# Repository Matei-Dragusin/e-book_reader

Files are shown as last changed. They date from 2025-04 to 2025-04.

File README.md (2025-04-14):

# README

## Diagrama bloc
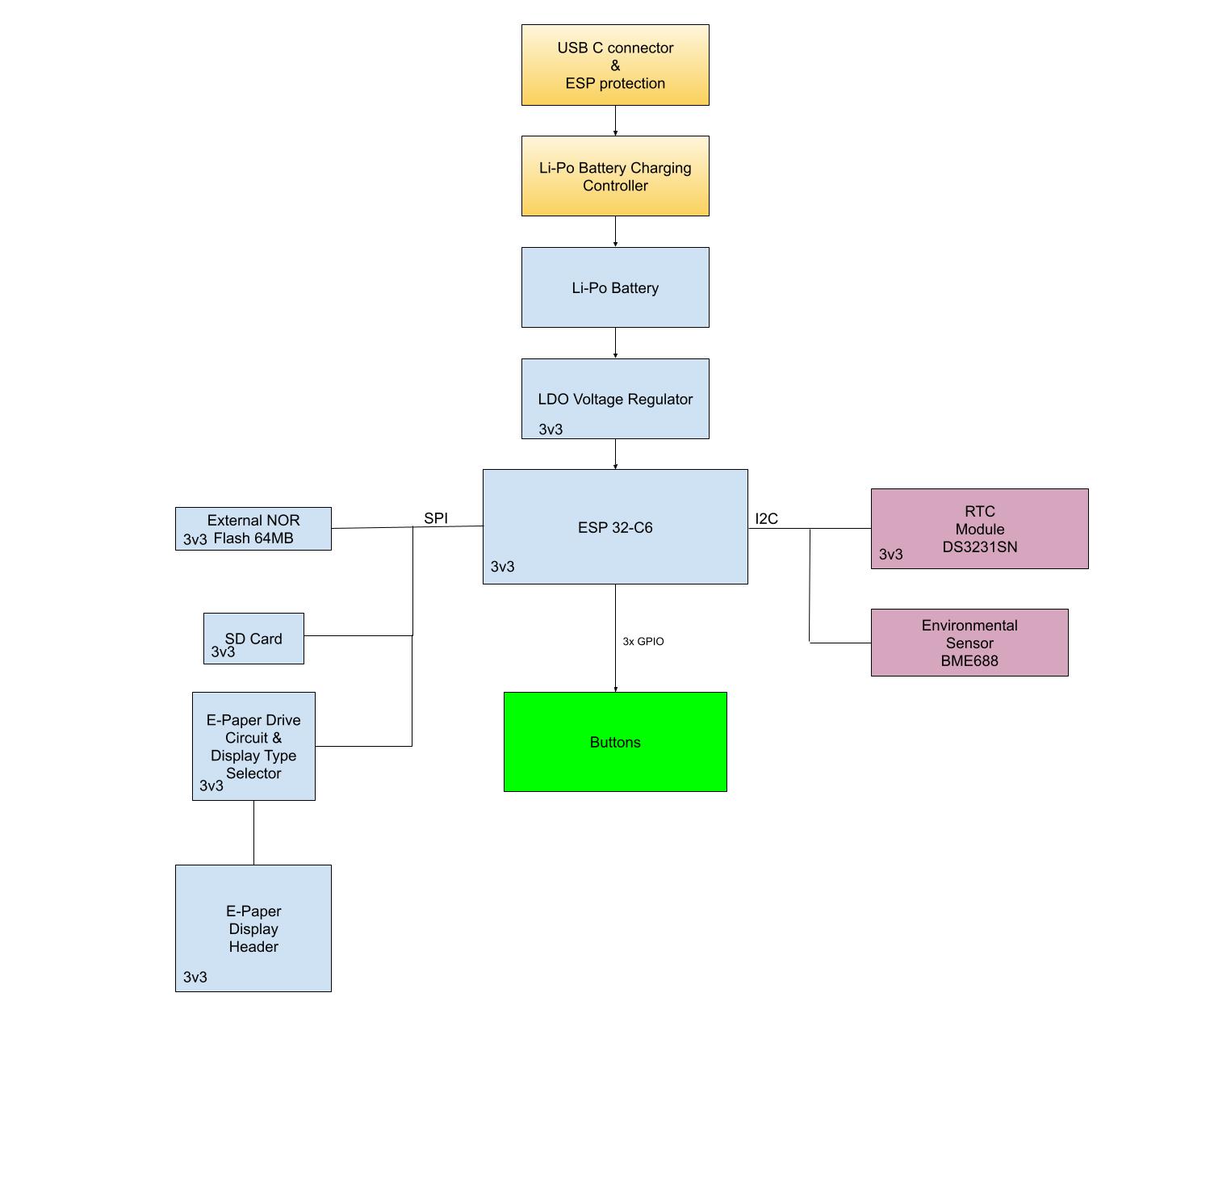
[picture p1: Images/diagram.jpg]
Diagrama Bloc
 

---
## Bill Of Materials (BOM)
| Componentă | Procurare | Datasheet |
|---|---|---|
| Button | [Mouser](https://ro.mouser.com/ProductDetail/CK/KMR221GULCLFS?qs=u2NJ%252B70r0goBXaNk7IrU0Q%3D%3D) |[Datasheet](https://www.ckswitches.com/media/1479/kmr2.pdf)|
| Capacitor SUPERCAP | [Mouser](https://ro.mouser.com/ProductDetail/Seiko-Semiconductors/CPH3225A?qs=3etwrb1wR%252BhUOph6lAO7eg%3D%3D) | [Datasheet](https://ro.mouser.com/datasheet/2/360/Seiko_Instruments_MicroBattery_E_20230330_2024Jan_-3561061.pdf)|
| Capacitor 100nF | [Mouser](https://ro.mouser.com/ProductDetail/KEMET/C0402C104K4RAL?qs=pIZUS6sqCWCaMuP2QVR%2Fog%3D%3D) | [Datasheet](https://ro.mouser.com/datasheet/2/447/KEM_C1018_X7R_SnPb_SMD-3316276.pdf)|
| Capacitor 4.7uF | [Mouser](https://ro.mouser.com/ProductDetail/KEMET/C0402C475M9PAC7411?qs=cpo3%2FpBou2jRzZxyxJnMGg%3D%3D) | [Datasheet](https://ro.mouser.com/datasheet/2/447/KEM_C1006_X5R_SMD-3316465.pdf)|
| Capacitor 100uF TANT | [Mouser](https://ro.mouser.com/ProductDetail/KYOCERA-AVX/TAJW107M010RNJ?qs=Wtp%252Bf%2FAeVqIH8v1VxV%252B1Rg%3D%3D) | [Datasheet](https://ro.mouser.com/datasheet/2/40/TAJ-3165264.pdf)|
| Capacitor 4.7uF / 25V | [Mouser](https://ro.mouser.com/ProductDetail/KYOCERA-AVX/12063C475KAZ2A?qs=%252BdQmOuGyFcG3LdbVp5waMw%3D%3D) | [Datasheet](https://ro.mouser.com/datasheet/2/40/X7RDielectric-2943470.pdf)|
| Capacitor 1uF | [Mouser](https://ro.mouser.com/ProductDetail/KEMET/C0402C105K9PACTU?qs=UdQET6xYxVCMExqTDkuPeQ%3D%3D) | [Datasheet](https://ro.mouser.com/datasheet/2/447/KEM_C1006_X5R_SMD-3316465.pdf)|
| Capacitor 10uF | [Mouser](https://ro.mouser.com/ProductDetail/KEMET/C0402C106M9PACTU?qs=x4XeXhDQKnp%252Bz0lMlwMC3A%3D%3D) | [Datasheet](https://ro.mouser.com/datasheet/2/447/KEM_C1006_X5R_SMD-3316465.pdf)|
| CHG_LED | [CPC](https://cpc.farnell.com/kingbright/kpg-1608zgc/led-smd-0603-grn/dp/SC20796) | [Datasheet](https://www.farnell.com/datasheets/2046349.pdf)|
| USBLC6-2SC6Y | [Mouser](https://ro.mouser.com/ProductDetail/STMicroelectronics/USBLC6-2SC6Y?qs=gNDSiZmRJS%2FOgDexvXkdow%3D%3D) | [Datasheet](https://ro.mouser.com/datasheet/2/389/usblc6_2sc6y-1852505.pdf)|
| PGB1010603MR | [Mouser](https://ro.mouser.com/ProductDetail/Littelfuse/PGB1010603MR?qs=gu7KAQ731URLg4GSnNNN7Q%3D%3D) | [Datasheet](https://www.littelfuse.com/assetdocs/pulseguard-esd-suppressors-pgb1-datasheet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)|
| SD0805S020S1R0 | [Mouser](https://ro.mouser.com/ProductDetail/KYOCERA-AVX/SD0805S020S1R0?qs=jCA%252BPfw4LHbpkAoSnwrdjw%3D%3D) | [Datasheet](https://ro.mouser.com/datasheet/2/40/schottky-3165252.pdf)|
| MBR0530 | [Mouser](https://ro.mouser.com/ProductDetail/onsemi/MBR0530T3G?qs=3JMERSakebpEmdUS6GetdQ%3D%3D) | [Datasheet](https://www.onsemi.com/products/discrete-power-modules/schottky-diodes-schottky-rectifiers/mbr0530t3g)|
| Capacitor 1uF / 50V | [Mouser](https://ro.mouser.com/ProductDetail/TDK/C1608X7R1H105K080AB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) | [Datasheet](https://product.tdk.com/system/files/dam/doc/product/capacitor/ceramic/mlcc/catalog/mlcc_commercial_general_en.pdf)|
| Capacitor 0.1uF / 50V | [Farnell](https://ro.farnell.com/multicomp-pro/mcmlr50v104kx7r/ceramic-capacitor-0-1uf-50v-x7r/dp/1600875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) | [Datasheet](https://www.farnell.com/datasheets/2873577.pdf?_gl=1*x28a2*_gcl_au*MTYwODAzNzc2OC4xNzQzNDM1MjM4)|
| BD5229G-TR | [Mouser](https://ro.mouser.com/ProductDetail/ROHM-Semiconductor/BD5229G-TR?qs=4kLU8WoGk0vvnhrrYwdszw%3D%3D) | [Datasheet](https://fscdn.rohm.com/en/products/databook/datasheet/ic/power/voltage_detector/bd52xxg-e.pdf)|
| XC6220A331MR-G | [Mouser](https://ro.mouser.com/ProductDetail/Torex-Semiconductor/XC6220A331MR-G?qs=AsjdqWjXhJ8ZSWznL1J0gg%3D%3D) | [Datasheet](https://ro.mouser.com/datasheet/2/760/xc6220-3371556.pdf)|
| FH34SRJ-24S-0.5SH_99_ | [Mouser](https://ro.mouser.com/ProductDetail/Hirose-Connector/FH34SRJ-24S-0.5SH99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) | [Datasheet](https://ro.mouser.com/datasheet/2/185/FH34SRJ_24S_0_5SH_99__CL0580_1255_6_99_2DDrawing_0-1615044.pdf)|
| SAMACSYS_PARTS_USB4110-GF-A | [Mouser](https://ro.mouser.com/ProductDetail/GCT/USB4110-GF-A?qs=KUoIvG%2F9IlYiZvIXQjyJeA%3D%3D) | [Datasheet](https://ro.mouser.com/datasheet/2/837/GCT_USB4110_Product_Drawing___20k_cycles-3455479.pdf)|
| QWIIC_RIGHT_ANGLEA | [Mouser](https://ro.mouser.com/ProductDetail/JST-Commercial/SM04B-SRSS-TBLFSN?qs=cdbOS8ANM9B3FdyA6cNU2A%3D%3D) | [Datasheet](https://ro.mouser.com/datasheet/2/564/eSR_SZ-3476820.pdf)|
| 112A-TAAR-R03_ATTEND | [LCSC](https://www.lcsc.com/product-detail/SD-Card-Connectors_Attend-Technology-112A-TAAR-R03_C6970445.html) | [Datasheet](https://www.lcsc.com/datasheet/lcsc_datasheet_2411220717_Attend-Technology-112A-TAAR-R03_C6970445.pdf)|
| Bobina | [Mouser](https://ro.mouser.com/ProductDetail/Wurth-Elektronik/744043680?qs=PGXP4M47uW6VkZq%252BkzjrHA%3D%3D) | [Datasheet](https://www.we-online.com/components/products/datasheet/744043680.pdf)|
| MCP73831 | [Mouser](https://ro.mouser.com/ProductDetail/Microchip-Technology/MCP73831-2ACI-MC?qs=hH%252BOa0VZEiBneYTVdpuVdg%3D%3D) | [Datasheet](https://ro.mouser.com/datasheet/2/268/MCP73831_Family_Data_Sheet_DS20001984H-3441711.pdf)|
| PFMF.050.1 | [Mouser](https://ro.mouser.com/ProductDetail/Schurter/PFMF.050.2?qs=1auRipcfynCums5v1iucSA%3D%3D) | [Datasheet](https://ro.mouser.com/datasheet/2/358/typ_PFMF-1275918.pdf)|
| DMG2305UX-7 | [Mouser](https://ro.mouser.com/ProductDetail/Diodes-Incorporated/DMG2305UX-7?qs=L1DZKBg7t5F%2FNBHrjfxC%252Bg%3D%3D) | [Datasheet](https://www.diodes.com/assets/Datasheets/DMG2305UX.pdf)|
| SI1308EDL-T1-GE3 | [Mouser](https://ro.mouser.com/ProductDetail/Vishay-Semiconductors/SI1308EDL-T1-GE3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) | [Datasheet](https://www.vishay.com/docs/63399/si1308edl.pdf)|
| Resistor 10K | [DigiKey](https://www.digikey.com/en/products/detail/venkel/CR0402-10W-102JT/12332774) | [Datasheet](https://data.venkel.com/documents/cr-series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.)|
| Resistor 100K | [Venkel](https://venkel.com/part/CR0402-16W-1003FT) | [Datasheet](https://data.venkel.com/documents/cr-series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.)|
| Resistor 5k1 | [Venkel](https://venkel.com/part/CR0402-10W-5101FT) | [Datasheet](https://data.venkel.com/documents/cr-series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.)|
| Resistor 2k | [Venkel](https://www.venkel.com/part/CR0402-16W-2002FT) | [Datasheet](https://data.venkel.com/documents/cr-series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.)|
| Resistor 0.47 | [Mouser](https://ro.mouser.com/ProductDetail/Vishay-Beyschlag/MCT06030C4700FP500?qs=XsZ9OvPb0dt82KlzjdcMjQ%3D%3D) | [Datasheet](https://www.vishay.com/docs/28705/mcx0x0xpro.pdf)|
| BME688 | [Mouser](https://ro.mouser.com/ProductDetail/Bosch-Sensortec/BME688?qs=IS%252B4QmGtzzqQoVDscqwx3A%3D%3D) | [Datasheet](https://ro.mouser.com/datasheet/2/783/bst_bme688_fl000-2307034.pdf)|
| W25Q512JVEIQ | [Mouser](https://ro.mouser.com/ProductDetail/Winbond/W25Q512JVEIQ?qs=l7cgNqFNU1jw6svr3at6tA%3D%3D) | [Datasheet](https://ro.mouser.com/datasheet/2/949/Winbond_W25Q512JV_Datasheet-3240039.pdf)|
| ESP32-C6-WROOM-1-N8 | [Mouser](https://ro.mouser.com/ProductDetail/Espressif-Systems/ESP32-C6-WROOM-1-N8?qs=8Wlm6%252BaMh8ST02Gmwp74cw%3D%3D) | [Datasheet](https://ro.mouser.com/datasheet/2/891/Espressif_ESP32_C6_WROOM_1__Datasheet_V0_1_PRELIMI-3239987.pdf)|
| DS3231SN# | [Mouser](https://ro.mouser.com/ProductDetail/Analog-Devices-Maxim-Integrated/DS3231SN?qs=1eQvB6Dk1vhUlr8%2FOrV0Fw%3D%3D) | [Datasheet](https://ro.mouser.com/datasheet/2/609/DS3231-3421123.pdf)|
| MAX17048G+T10 | [Mouser](https://ro.mouser.com/ProductDetail/Analog-Devices-Maxim-Integrated/MAX17048G%2bT10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) | [Datasheet](https://ro.mouser.com/datasheet/2/609/MAX17048_MAX17049-3469099.pdf)|
---
# Functionalitatea Hardware

**Sursa de Alimentare si Energie:**
- **USB cu ESD:** Protectie la alimentare si transfer de date.
- **Circuit de Incarcare Li-Po - MCP73831:** Managementul controlat al incarcarii pentru acumulatorul de 1800 mAh.
- **Baterie Li-Po & LDO Voltage Regulator:** Stabilizeaza tensiunea la 3.3V pentru componentele sistemului.

**Microcontroller & Interfete:**
- **ESP32-C6:**
    - **SPI:** Interconecteaza memoria NOR Flash, cardul SD și displayul e-paper.
    - **I2C:** Faciliteaza comunicarea cu RTC DS3231, senzorul BME688 și modulele aditionale.
    - **UART:** Dedicat pentru debugging și comunicatii seriale.
    - **GPIO:** Utilizat pentru butoane si puncte de testare.

**Module de Stocare & Afisare:**
- **Memorie NOR Flash (SPI):** Stocare eficienta pentru firmware si date operationale.
- **Card SD (SPI):** Ofera capacitate de stocare suplimentara.
- **E-Paper Display:** Asigura vizualizari precise cu consum energetic minim, operat prin SPI.

**Module Suplimentare & Senzori:**
- **RTC DS3231 (I2C):** Furnizeaza timpul real sistemului.
- **Senzor BME688 (I2C):** Monitorizeaza temperatura, umiditatea, presiunea si calitatea aerului.
- **Conector Qwiic/Stemma QT (I2C):** Faciliteaza integrarea modulelor aditionale.
- **Test Pads & Butoane (GPIO):** Suporta diagnosticarea si interactiunea directa.

**Optimizare Energetica:**
- **Mod Low-Power al ESP32-C6:** Optimizeaza consumul prin ajustarea dinamica a frecventei si ciclurilor active.
- **Stabilitate prin LDO:** Garanteaza o tensiune stabila de 3.3V.
- **Componente SMD (ex: capsula 0402):** Reduce consumul energetic prin dimensiuni compacte si eficienta ridicata.

---

# ESP32-C6 Pin Mapping

| Nume | GPIO | Utilizare | Observații |
|---|---|---|---|
| 3V3  | 3V3 | Alimentare 3.3V | Sursa de tensiune pentru ESP32-C6 și componente logice. |
| SCK (SPI) | IO6 | Clock pentru SPI | Asigură semnalul de ceas pentru transferuri rapide. |
| MOSI (SPI) | IO7 | Transmitere date SPI | Trimite date către NOR Flash, SD Card și E-Paper. |
| MISO (SPI) | IO2 | Recepție date SPI | Primește date de la dispozitivele SPI. |
| FLASH_CS | IO11 | Selectare SPI pentru NOR Flash | Selectează memoria NOR Flash pe magistrala SPI. |
| EPD_CS | IO10 | Selectare SPI pentru E-Paper | Selectează afișajul e-paper. |
| SDA (I2C) | IO21 | Linie de date I2C | Conectează RTC DS3231, senzorul BME688 și conectorul Qwiic/Stemma QT. |
| SCL (I2C) | IO22 | Linie de ceas I2C | Sincronizează comunicația I2C. |
| TX (UART) | TXD0/GPIO16 | Transmitere date UART | Utilizat pentru debug și comunicații seriale. |
| RX (UART) | RXD0/GPIO17 | Recepție date UART | Utilizat pentru debug și comunicații seriale. |
| Buton Reset | EN | Resetare ESP32-C6 | Pin dedicat pentru resetul sistemului. |
| Buton Boot | IO9 | Intrare în bootloader | Pin dedicat pentru a intra în modul boot. |
| Buton Change | IO15 | Schimbare mod operare | Permite comutarea între modurile de funcționare. |
| EPD DC | IO5 | Data/Command pentru E-Paper | Disting între semnal de comandă și semnal de date pentru afișaj. |
| EPD RST | IO23 | Resetare E-Paper | Resetează afișajul e-paper când este necesar. |
| EPD BUSY | IO3 | Indicator stare E-Paper | Semnal care indică dacă afișajul este ocupat. |
| INT_RTC | IO0 | Semnal de întrerupere de la RTC (DS3231) | Activează microcontrolerul. |
| 32KHZ | IO1 | Semnal de ceas 32 kHz | Linie de oscilație pentru DS3231 sau alt modul (nu intră direct în ESP). |
| SS_SD| IO4 | Chip Select pentru card SD (SPI) | Selectează cardul SD pe magistrala SPI. |
| USB_D- | IO12 | Linie diferențială USB (minus) | Conexiune la portul USB. |
| USB_D+ | IO13 | Linie diferențială USB (plus) | Conexiune la portul USB. |
| RTC_RST | IO18 | Reset extern/semnal RTC | Folosit pentru a reseta ceasul de timp real |
| I2C_PW | IO19 | Linia de alimentare / enable pentru I2C | Activează/dezactivează alimentarea senzorilor I2C pentru economisirea energiei. |
| EPD_3V3_C | IO20 | Linie de alimentare 3.3V pentru E-Paper | Această linie furnizează 3.3V specifice afișajului e-paper, separate de alimentarea principală, pentru stabilitatea semnalelor. |

---
## Motivatie

- **SPI** (SCK, MOSI, MISO, CS-uri) asigura transferul accelerat pentru memoria externa (Flash), cardul SD si ecranul e-paper.
- **I2C** (SDA, SCL) integreaza senzorii (RTC, BME688) si conectorul Qwiic, permitand utilizarea comuna a magistralei cu impact redus asupra consumului energetic.
- **UART** (TX, RX) este implementat pentru scopuri de debugging.
- **GPIO suplimentare** (butoane, test pads) ofera suport pentru controlul manual si procesele de diagnosticare.

---

## Pasii de Implementare

- **Schematic:** Am proiectat schematicul in concordanta cu specificatiile proiectului.
- **Redesenarea PCB-ului:** Am reconstruit placa PCB și am aranjat componentele conform referintei de design.
- **Autorutare:** Am implementat autorutarea pe ambele fete, cu grosimea traseelor de semnal de 0.15mm.
- **Net Class pentru Putere:** Am organizat traseele de alimentare intr-un netclass dedicat, le-am evidential cromatic si le-am dimensionat manual la 0.3mm pentru o distributie optima a energiei.
- **Planuri de Masă si Via Stitching:** Am implementat planurile de masă pe ambele fete si am aplicat via stitching in proximitatea modulului ESP pentru conexiuni eficiente intre straturi.
- **Modele 3D:** Am procurat modelele 3D ale componentelor de pe [ComponentSearchEngine](https://componentsearchengine.com/), le-am incorporat în Fusion 360 si le-am plasat adecvat pe PCB.
- **Integrarea in Carcasa:** Am incorporat placa in carcasa si am adaptat designul carcasei pentru a acomoda butoanele si conectorii.
- **Modelele 3D pentru Baterie si Display:** Am dezvoltat reprezentarile 3D pentru baterie si display, conectand conductorii la punctele de test corespunzatoare si asigurand pozitionarea optima in carcasa.
- **Export:** In etapa finala, am generat documentatia necesara - fisiere Gerber, Pick and Place (CPL) si BOM, pregatindu-le pentru procesul de fabricatie.

---

## Probleme Intampinate si Decizii de Acceptare a Erorilor

- **Erori SMD-Hole Board Outline Clearance la Mufa USB:**  
  Am identificat doua erori de tip SMD-Hole Board Outline Clearance asociate mufei USB. Aceste erori au fost considerate acceptabile conform indicatiilor tehnice primite.

---

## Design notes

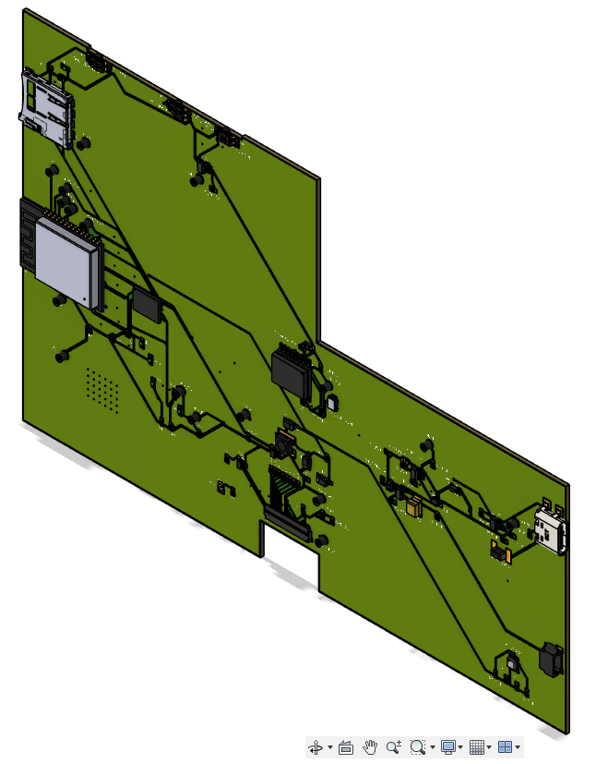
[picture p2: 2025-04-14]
Images/PCB-3D.png

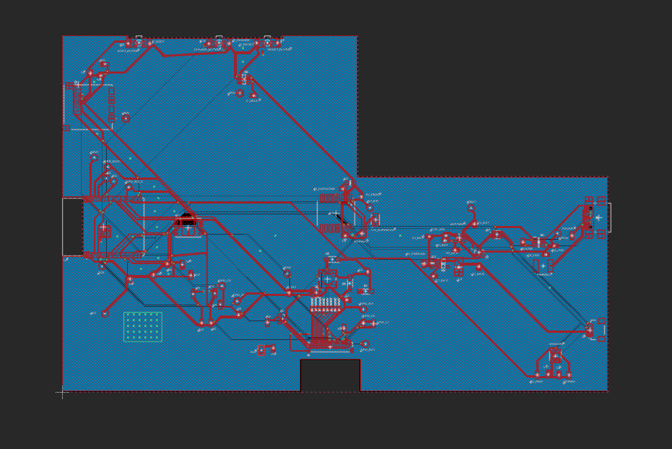
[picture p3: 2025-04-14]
Images/PCB-2D.png

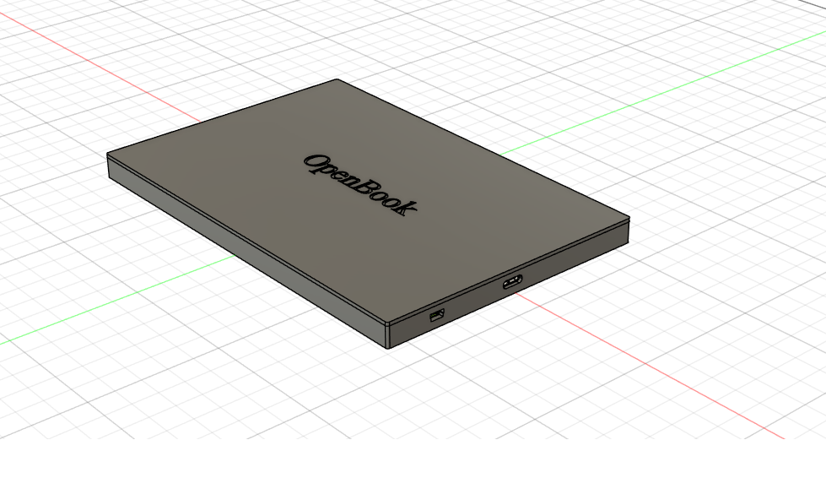
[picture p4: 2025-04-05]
Images/3D.png

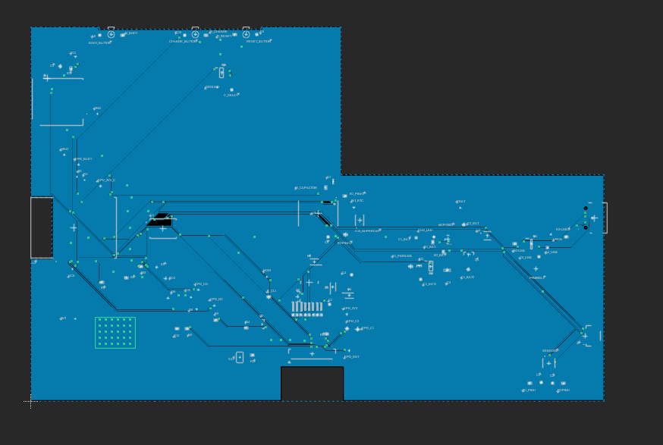
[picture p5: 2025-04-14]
Images/PCB-2D-BOTTOM.png

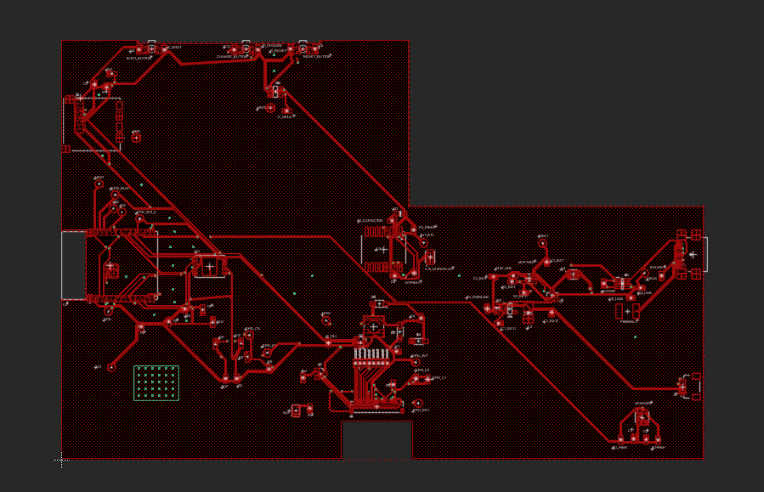
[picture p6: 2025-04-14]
Images/PCB-2D-TOP.png

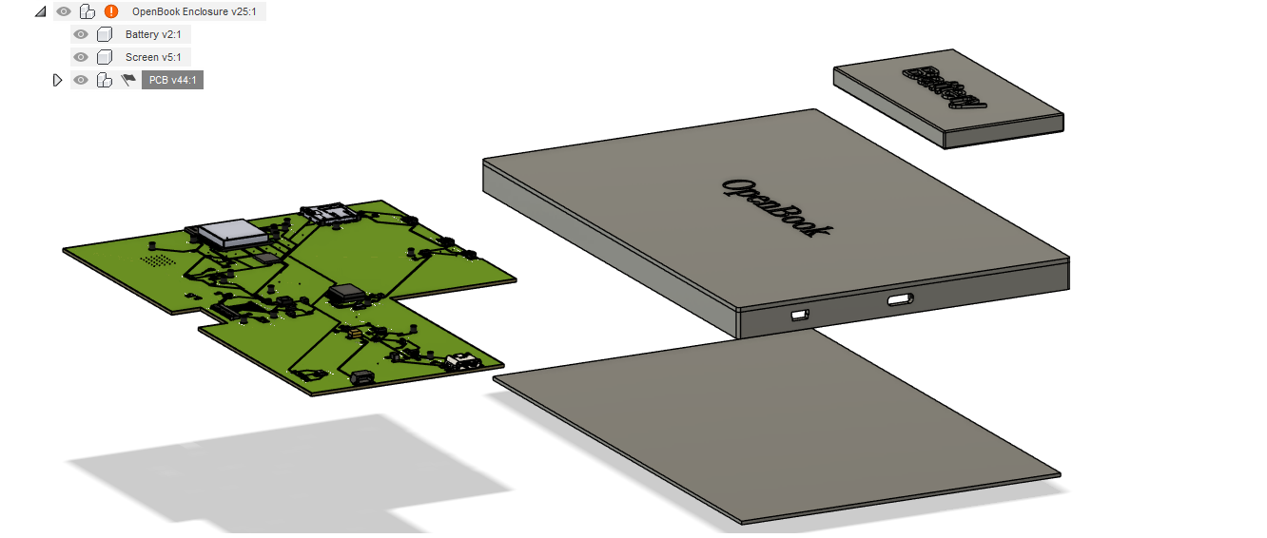
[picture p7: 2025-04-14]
Images/Exploded3D.png

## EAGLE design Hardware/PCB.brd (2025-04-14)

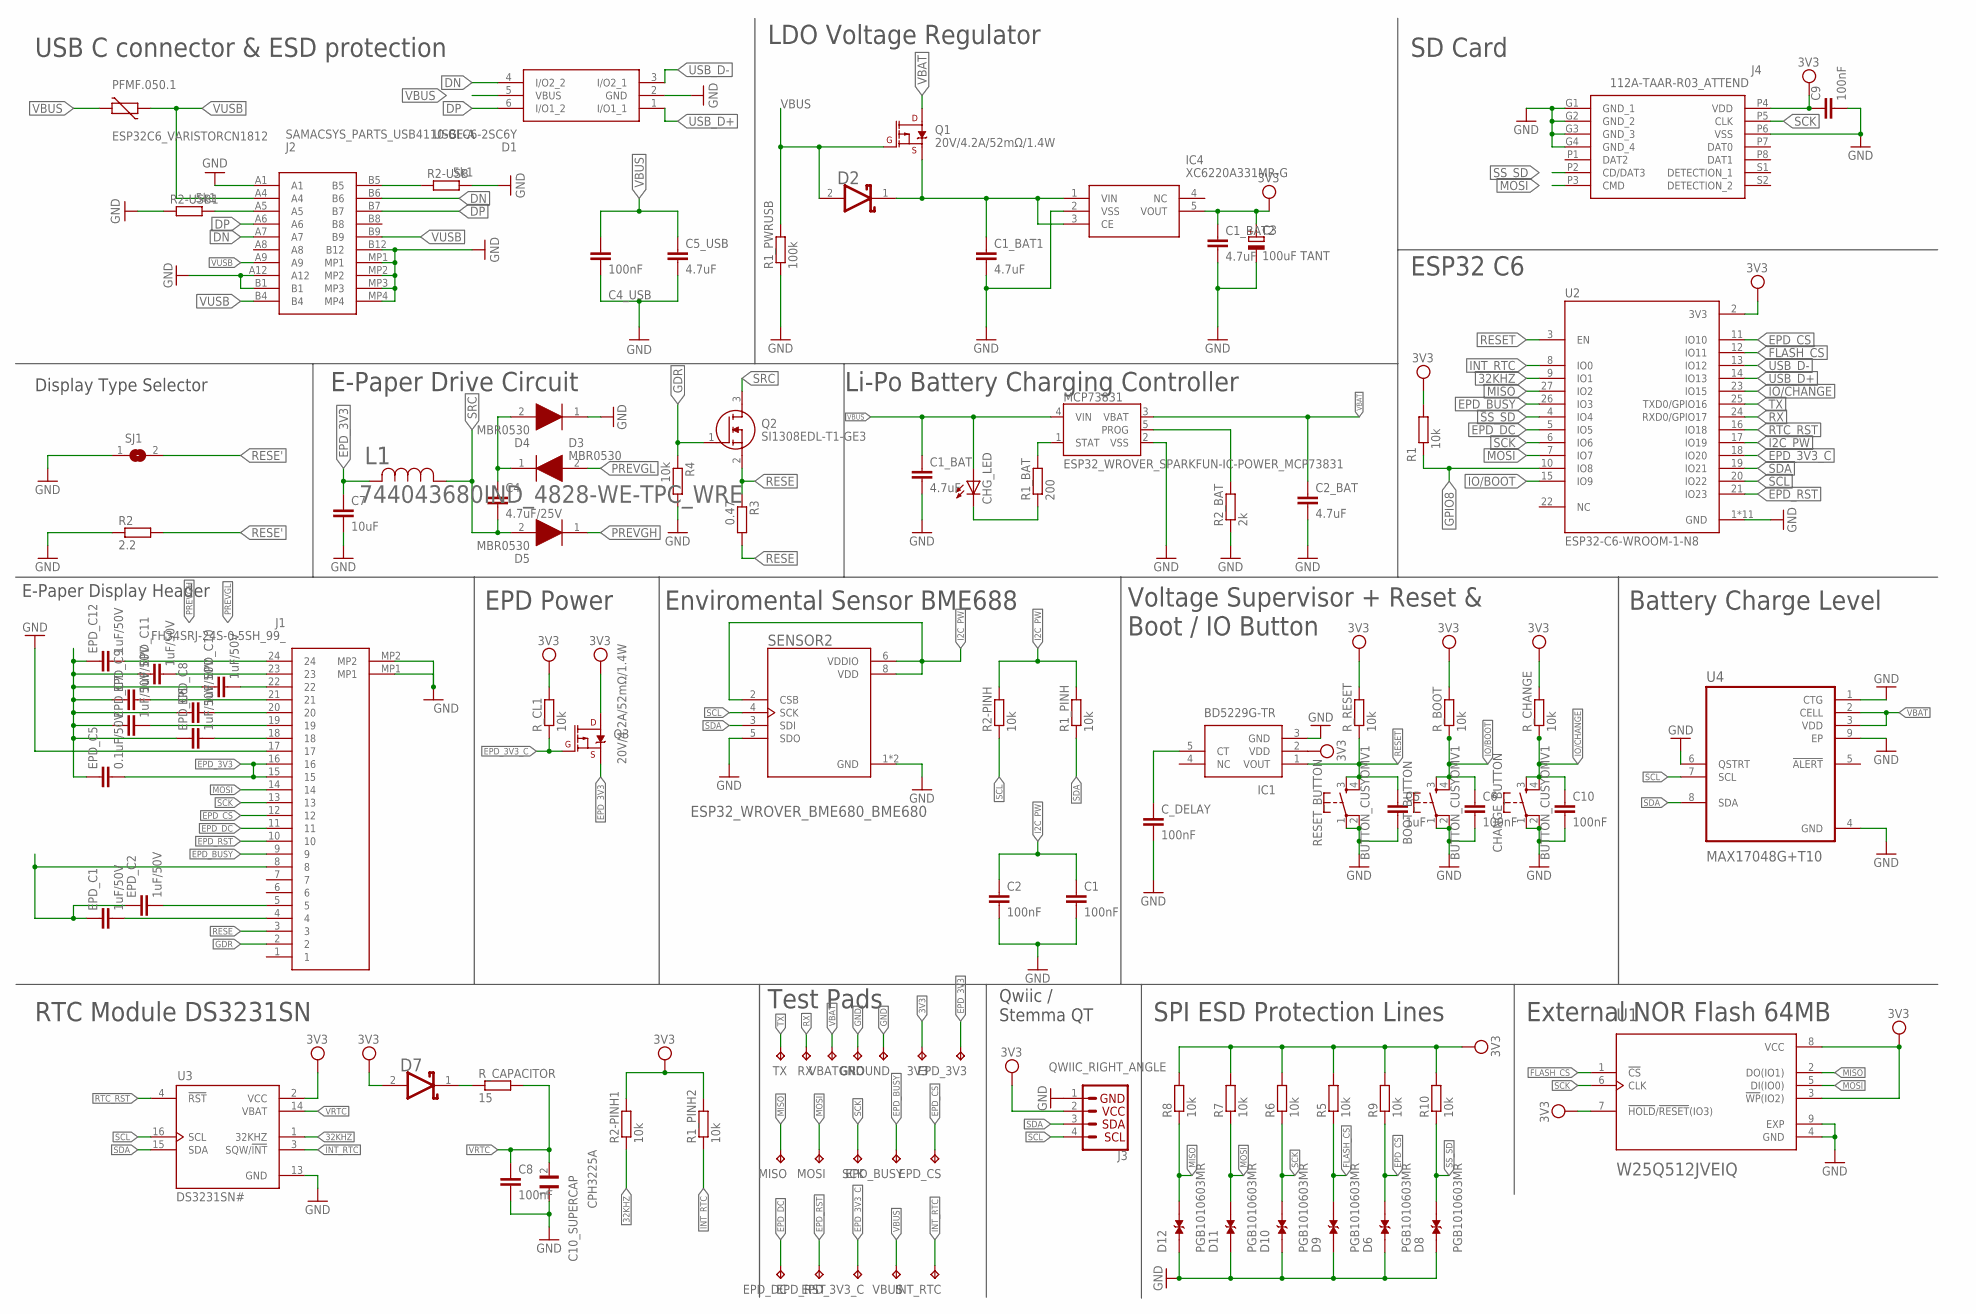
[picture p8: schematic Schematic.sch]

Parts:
3V3: TPTP20R; TP20R
BOOT_BUTTON: BUTTON_CUSYOMV1; MYBUTTON
C1, C2, C4_USB, C6, C8, C9, C10: 100nF; EAGLE-LTSPICE_C0402
C1_BAT, C1_BAT1, C1_BAT2, C2_BAT, C5_USB: 4.7uF; EAGLE-LTSPICE_C0402
C3: 100uF TANT; RCL_CT3528
C4: 4.7uF/25V; EAGLE-LTSPICE_C0402
C5: 1uF; EAGLE-LTSPICE_C0402
C7: 10uF; EAGLE-LTSPICE_C0402
C10_SUPERCAP: CPH3225A; CAPCP3225X100N
CHANGE_BUTTON: BUTTON_CUSYOMV1; MYBUTTON
CHG_LED: ADAFRUIT_LEDCHIP-LED0603; ADAFRUIT_CHIP-LED0603
C_DELAY: 100nF; EAGLE-LTSPICE_C0402
D1: USBLC6-2SC6Y; SOT95P280X145-6N
D2, D7: ESP32_WROVER_AVX---SD0805S020S1R0_AVX_SD0805S020S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; ESP32_WROVER_AVX---SD0805S020S1R0_AVX_SD0805S020S1R0_0
D3, D4, D5: MBR0530; SOD3716X135N
D6, D8, D9, D10, D11, D12: PGB1010603MR; DIOC1608X36N
EPD_3V3, EPD_3V3_C: TPTP20R; TP20R
EPD_BUSY: TPTP20R; TP20R
EPD_C1, EPD_C2, EPD_C6, EPD_C7, EPD_C8, EPD_C9, EPD_C10, EPD_C11, EPD_C12: 1uF/50V; EAGLE-LTSPICE_C0402
EPD_C5: 0.1uF/50V; EAGLE-LTSPICE_C0402
EPD_CS: TPTP20R; TP20R
EPD_DC: TPTP20R; TP20R
EPD_RST: TPTP20R; TP20R
GND: TPTP20R; TP20R
GROUND: TPTP20R; TP20R
IC1: BD5229G-TR; SOT95P280X125-5N
IC4: XC6220A331MR-G; SOT95P280X120-5N
INT_RTC: TPTP20R; TP20R
J1: FH34SRJ-24S-0.5SH_99_; FH34SRJ24S05SH99
J2: SAMACSYS_PARTS_USB4110-GF-A; SAMACSYS_PARTS_USB4110GFA
J3: QWIIC_RIGHT_ANGLE; JST04_1MM_RA
J4: 112A-TAAR-R03_ATTEND; 112ATAARR03ATTEND
L1: 744043680IND_4828-WE-TPC_WRE; IND_4828-WE-TPC_WRE
MCP73831: ESP32_WROVER_SPARKFUN-IC-POWER_MCP73831; ESP32_WROVER_SPARKFUN-IC-POWER_SOT23-5
MISO: TPTP20R; TP20R
MOSI: TPTP20R; TP20R
PFMF.050.1: ESP32C6_VARISTORCN1812; ESP32C6_VARISTOR_CT/CN1812
Q1, Q3: 20V/4.2A/52mΩ/1.4W; ESP32_WROVER_SPARKFUN-DISCRETESEMI_SOT23-3
Q2: SI1308EDL-T1-GE3; ESP32_WROVER_SPARKFUN-DISCRETESEMI_SOT23-3
R1, R1_PINH, R1_PINH2, R2-PINH, R2-PINH1, R4, R5, R6, R7, R8, R9, R10: 10k; ESP32_WROVER_EAGLE-LTSPICE_R0402
R1_BAT: 200; ESP32_WROVER_EAGLE-LTSPICE_R0402
R1_PWRUSB: 100k; ESP32_WROVER_EAGLE-LTSPICE_R0402
R2: 2.2; ESP32_WROVER_EAGLE-LTSPICE_R0402
R2-USB, R2-USB1: 5k1; ESP32_WROVER_EAGLE-LTSPICE_R0402
R2_BAT: 2k; ESP32_WROVER_EAGLE-LTSPICE_R0402
R3: 0.47; ESP32_WROVER_EAGLE-LTSPICE_R0402
RESET_BUTTON: BUTTON_CUSYOMV1; MYBUTTON
RX: TPTP20R; TP20R
R_BOOT: 10k; ESP32_WROVER_EAGLE-LTSPICE_R0402
R_CAPACITOR: 15; ESP32_WROVER_EAGLE-LTSPICE_R0402
R_CHANGE: 10k; ESP32_WROVER_EAGLE-LTSPICE_R0402
R_CL1: 10k; ESP32_WROVER_EAGLE-LTSPICE_R0402
R_RESET: 10k; ESP32_WROVER_EAGLE-LTSPICE_R0402
SCK: TPTP20R; TP20R
SENSOR2: ESP32_WROVER_BME680_BME680; ESP32_WROVER_BME680_PSON80P300X300X100-8N
SJ1: SJ
TX: TPTP20R; TP20R
U1: W25Q512JVEIQ; SON127P600X800X80-9N
U2: ESP32-C6-WROOM-1-N8; XCVR_ESP32-C6-WROOM-1-N8
U3: DS3231SN#; SOIC127P1032X265-16N
U4: MAX17048G+T10; SON50P200X200X80-9N
VBAT: TPTP20R; TP20R
VBUS: TPTP20R; TP20R

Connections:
3V3: 3V3.TP, C1_BAT2.1, C3.+, C9.1, D7.2 (ANODE), IC1.2 (VDD), IC4.5 (VOUT), J3.2, J4.P4 (VDD), Q3.3 (D), R1.2, R1_PINH2.2, R2-PINH1.2, R5.2, R6.2, R7.2, R8.2, R9.2, R10.2, R_BOOT.2, R_CHANGE.2, R_CL1.2, R_RESET.2, U1.3 (!WP!(IO2)), U1.7 (!HOLD!/!RESET!(IO3)), U1.8 (VCC), U2.2 (3V3), U3.2 (VCC)
32KHZ: R2-PINH1.1, U2.9 (IO1), U3.1 (32KHZ)
DN: D1.4 (I/O2_2), J2.A7, J2.B6
DP: D1.6 (I/O1_2), J2.A6, J2.B7
EPD_3V3: C7.1, EPD_3V3.TP, EPD_C5.2, J1.15, J1.16, L1.2, Q3.2 (S)
EPD_3V3_C: EPD_3V3_C.TP, Q3.1 (G), R_CL1.1, U2.18 (IO20)
EPD_BUSY: EPD_BUSY.TP, J1.9, U2.26 (IO3)
EPD_CS: D6.2, EPD_CS.TP, J1.12, R9.1, U2.11 (IO10)
EPD_DC: EPD_DC.TP, J1.11, U2.5 (IO5)
EPD_RST: EPD_RST.TP, J1.10, U2.21 (IO23)
FLASH_CS: D9.2, R5.1, U1.1 (!CS), U2.12 (IO11)
GDR: J1.2, Q2.1 (G), R4.1
GND: BOOT_BUTTON.1, BOOT_BUTTON.2, C1.2, C1_BAT.2, C1_BAT1.2, C1_BAT2.2, C2.2, C2_BAT.2, C3.-, C4_USB.2, C5.2, C5_USB.2, C6.2, C7.2, C8.2, C9.2, C10.2, C10_SUPERCAP.1, CHANGE_BUTTON.1, CHANGE_BUTTON.2, C_DELAY.2, D1.2 (GND), D4.1 (K), D6.1, D8.1, D9.1, D10.1, D11.1, D12.1, GND.TP, GROUND.TP, IC1.3 (GND), IC4.2 (VSS), J1.17, J1.MP1, J1.MP2, J2.A1, J2.A12, J2.B1, J2.B12, J2.MP1, J2.MP2, J2.MP3, J2.MP4, J3.1, J4.G1 (GND_1), J4.G2 (GND_2), J4.G3 (GND_3), J4.G4 (GND_4), J4.P6 (VSS), MCP73831.2 (VSS), R1_PWRUSB.1, R2.1, R2-USB.2, R2-USB1.1, R2_BAT.1, R4.2, RESET_BUTTON.1, RESET_BUTTON.2, SENSOR2.1 (GND), SENSOR2.5 (SDO), SENSOR2.7 (GND), SJ1.1, U1.4 (GND), U1.9 (EXP), U2.1 (GND), U2.28 (GND), U2.29_1 (GND), U2.29_2 (GND), U2.29_3 (GND), U2.29_4 (GND), U2.29_5 (GND), U2.29_6 (GND), U2.29_7 (GND), U2.29_8 (GND), U2.29_9 (GND), U3.13 (GND), U4.1 (CTG), U4.4 (GND), U4.6 (QSTRT), U4.9 (EP)
GPIO8: R1.1, U2.10 (IO8)
I2C_PW: C1.1, C2.1, R1_PINH.2, R2-PINH.2, SENSOR2.2 (CSB), SENSOR2.6 (VDDIO), SENSOR2.8 (VDD), U2.17 (IO19)
INT_RTC: INT_RTC.TP, R1_PINH2.1, U2.8 (IO0), U3.3 (SQW/!INT)
IO/BOOT: BOOT_BUTTON.3, BOOT_BUTTON.4, C6.1, U2.15 (IO9)
IO/CHANGE: C10.1, CHANGE_BUTTON.3, CHANGE_BUTTON.4, U2.23 (IO15)
MISO: D12.2, MISO.TP, R8.1, U1.2 (DO(IO1)), U2.27 (IO2)
MOSI: D11.2, J1.14, J4.P3 (CMD), MOSI.TP, R7.1, U1.5 (DI(IO0)), U2.7 (IO7)
unnamed: J2.A5, R2-USB1.2
unnamed: J2.B5, R2-USB.1
unnamed: C1_BAT1.1, D2.1 (CATHODE), IC4.1 (VIN), IC4.3 (CE), Q1.2 (S)
unnamed: EPD_C2.2, J1.5
unnamed: EPD_C5.1, EPD_C6.1, EPD_C7.1, EPD_C8.1, EPD_C9.1, EPD_C10.1, EPD_C11.1, EPD_C12.1
unnamed: C_DELAY.1, IC1.5 (CT)
unnamed: C4.1, D3.1 (K), D4.2 (A)
unnamed: CHG_LED.C, R1_BAT.1
unnamed: MCP73831.1 (STAT), R1_BAT.2
unnamed: EPD_C12.2, J1.24
unnamed: MCP73831.5 (PROG), R2_BAT.2
unnamed: D7.1 (CATHODE), R_CAPACITOR.1
unnamed: EPD_C10.2, J1.22
unnamed: EPD_C8.2, J1.20
unnamed: EPD_C7.2, J1.19
unnamed: EPD_C6.2, J1.18
unnamed: EPD_C1.1, EPD_C2.1, J1.8
unnamed: EPD_C1.2, J1.4
PREVGH: D5.1 (K), EPD_C9.2, J1.21
PREVGL: D3.2 (A), EPD_C11.2, J1.23
RESE: J1.3, Q2.2 (S), R3.1
RESE': R2.2, SJ1.2
RESET: C5.1, IC1.1 (VOUT), RESET_BUTTON.3, RESET_BUTTON.4, R_RESET.1, U2.3 (EN)
RESET1: R_CHANGE.1
RESET2: R_BOOT.1
RTC_RST: U2.16 (IO18), U3.4 (!RST)
RX: RX.TP, U2.24 (RXD0/GPIO17)
SCK: D10.2, J1.13, J4.P5 (CLK), R6.1, SCK.TP, U1.6 (CLK), U2.6 (IO6)
SCL: J3.4, R2-PINH.1, SENSOR2.4 (SCK), U2.20 (IO22), U3.16 (SCL), U4.7 (SCL)
SDA: J3.3, R1_PINH.1, SENSOR2.3 (SDI), U2.19 (IO21), U3.15 (SDA), U4.8 (SDA)
SRC: C4.2, D5.2 (A), L1.1, Q2.3 (D)
SS_SD: D8.2, J4.P2 (CD/DAT3), R10.1, U2.4 (IO4)
TX: TX.TP, U2.25 (TXD0/GPIO16)
USB_D+: D1.1 (I/O1_1), U2.14 (IO13)
USB_D-: D1.3 (I/O2_1), U2.13 (IO12)
VBAT: C2_BAT.1, MCP73831.3 (VBAT), Q1.3 (D), U4.2 (CELL), U4.3 (VDD), VBAT.TP
VBUS: C1_BAT.1, C4_USB.1, C5_USB.1, CHG_LED.A, D1.5 (VBUS), D2.2 (ANODE), MCP73831.4 (VIN), Q1.1 (G), R1_PWRUSB.2, VBUS.TP
VRTC: C8.1, C10_SUPERCAP.2, R_CAPACITOR.2, U3.14 (VBAT)
VUSB: J2.A4, J2.A9, J2.B4, J2.B9, PFMF.050.1.1

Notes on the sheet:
Display Type Selector
E-Paper Display Header
USB C connector & ESD protection
LDO Voltage Regulator
SD Card
E-Paper Drive Circuit
Li-Po Battery Charging Controller
ESP32 C6
EPD Power
Enviromental Sensor BME688
Voltage Supervisor + Reset & Boot / IO Button
Battery Charge Level
RTC Module DS3231SN
Test Pads
Qwiic / Stemma QT
External NOR Flash 64MB
SPI ESD Protection Lines

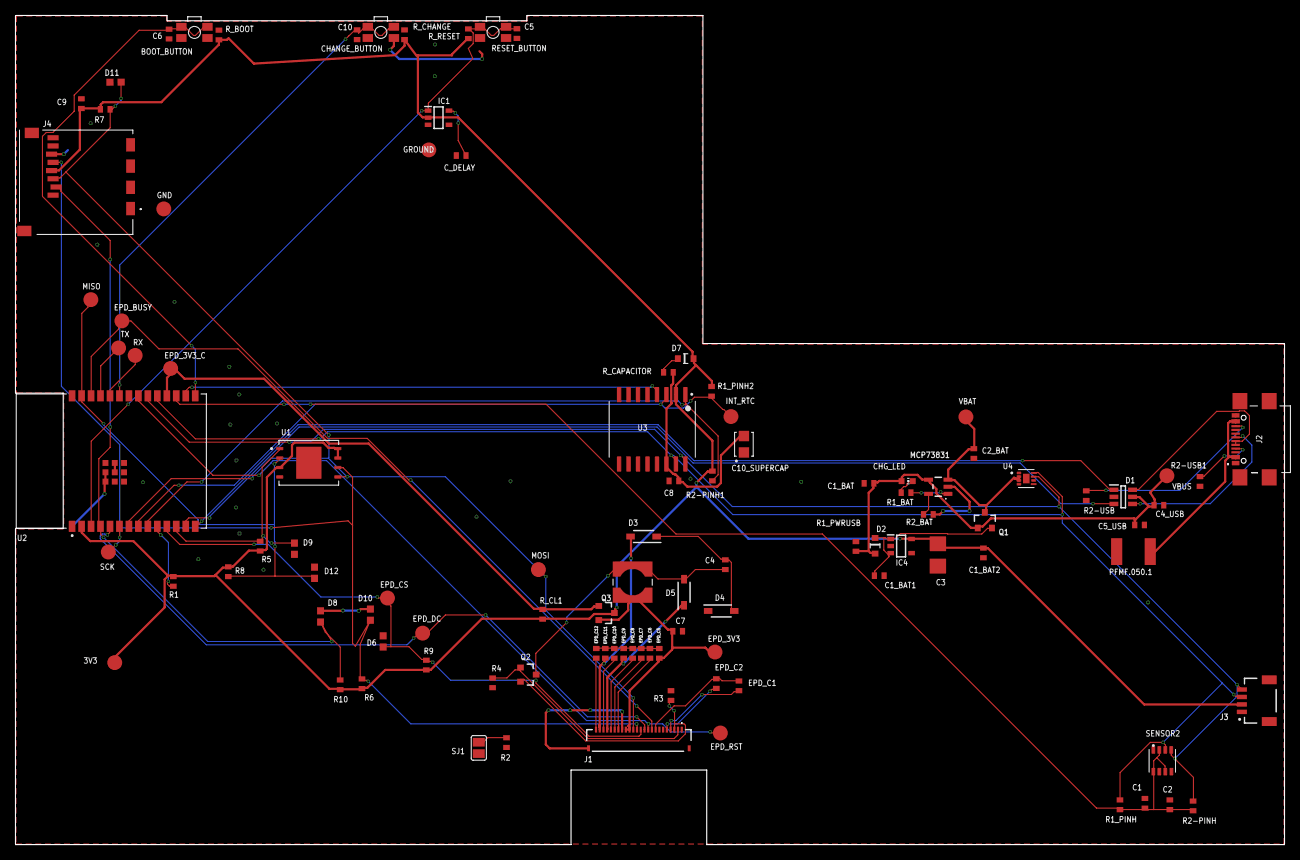
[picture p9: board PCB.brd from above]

Board: 2 copper layers, 170.2 x 111.2 mm, 103 parts (0 on the bottom side), 57 nets.

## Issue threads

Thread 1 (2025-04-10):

[PCB 2D] Fix GND pour

NickZaharia308, 2025-04-10:
# Description
There are places on the PCB that don't connect with GND

# Solution
Add GND vias on those places

# Example
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

Closed 2025-04-14.

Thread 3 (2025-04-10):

[PCB 2D] Modify the thickness of PCB

NickZaharia308, 2025-04-10:
# Description
The width of PCB should be **1mm** as stated in the task. (So that it matches the enclosure)

# Solution
Modify the thickness of PCB

# Example

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

Closed 2025-04-14.

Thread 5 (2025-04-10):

[3D model] Battery missing in the exploded view

NickZaharia308, 2025-04-10:
# Description
The battery is missing from the [exploded view](https://github.com/Matei-Dragusin/e-book_reader/blob/main/Images/Exploded3D.png)

# Solution
Add the battery as stated in the [task](https://ocw.cs.pub.ro/courses/tsc/proiect2025)

# Attachments

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

Closed 2025-04-14.

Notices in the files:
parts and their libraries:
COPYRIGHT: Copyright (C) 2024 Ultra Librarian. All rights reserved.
